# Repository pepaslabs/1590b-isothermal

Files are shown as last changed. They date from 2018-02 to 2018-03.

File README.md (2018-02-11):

# 1590b-isothermal

A "daughter board" which attaches to the bottom of a Hammond 1590B and regulates its temperature at 25C.

- [schematic](kicad/releases/v1/isothermal.pdf)
- [gerber files](kicad/releases/v1)
- [OSHPark link](https://oshpark.com/shared_projects/qRlewBCr)

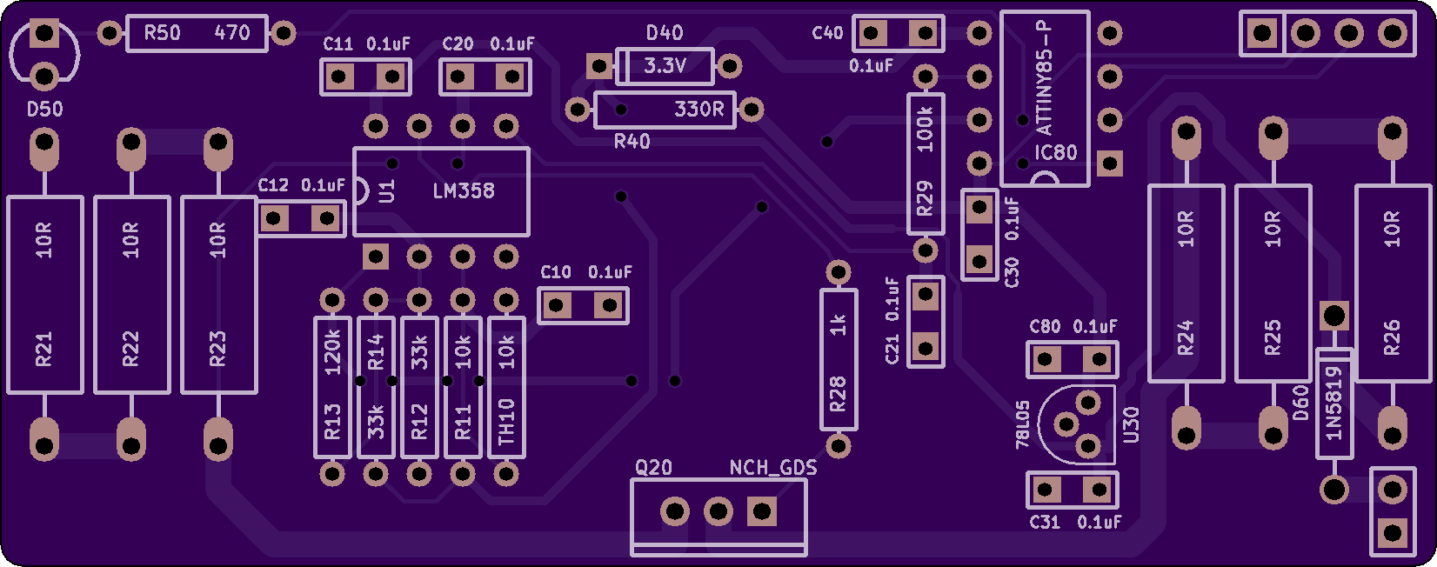
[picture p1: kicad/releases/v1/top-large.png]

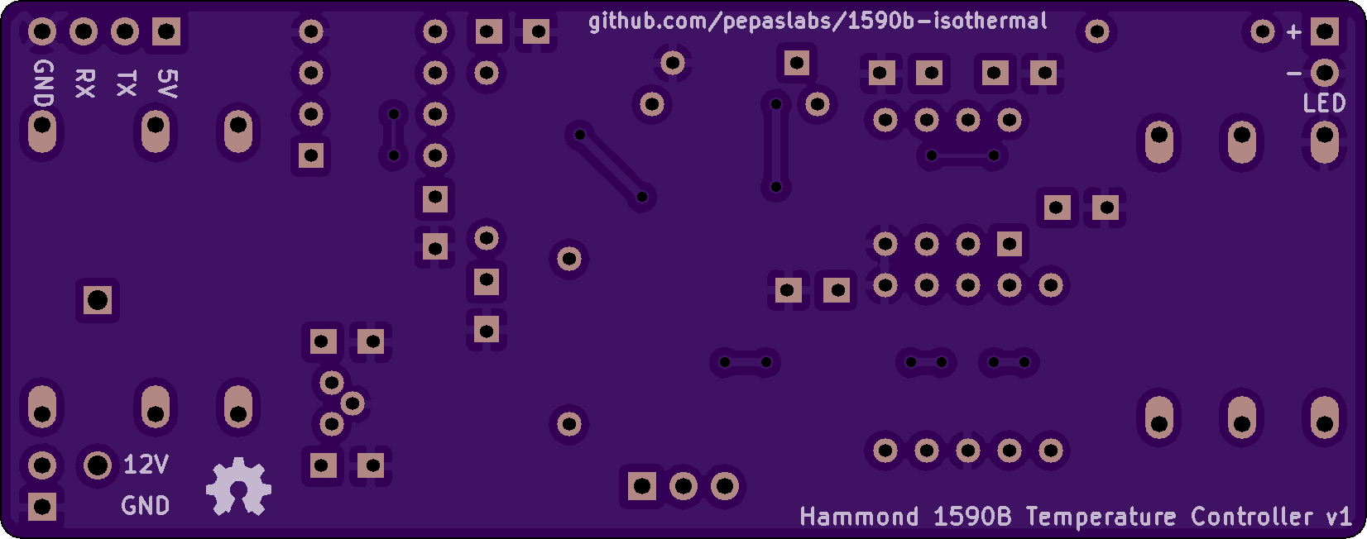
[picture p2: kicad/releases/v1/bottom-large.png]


The resistor values were chosen to map a 20C to 30C window onto (roughly) 0V to 3.3V.

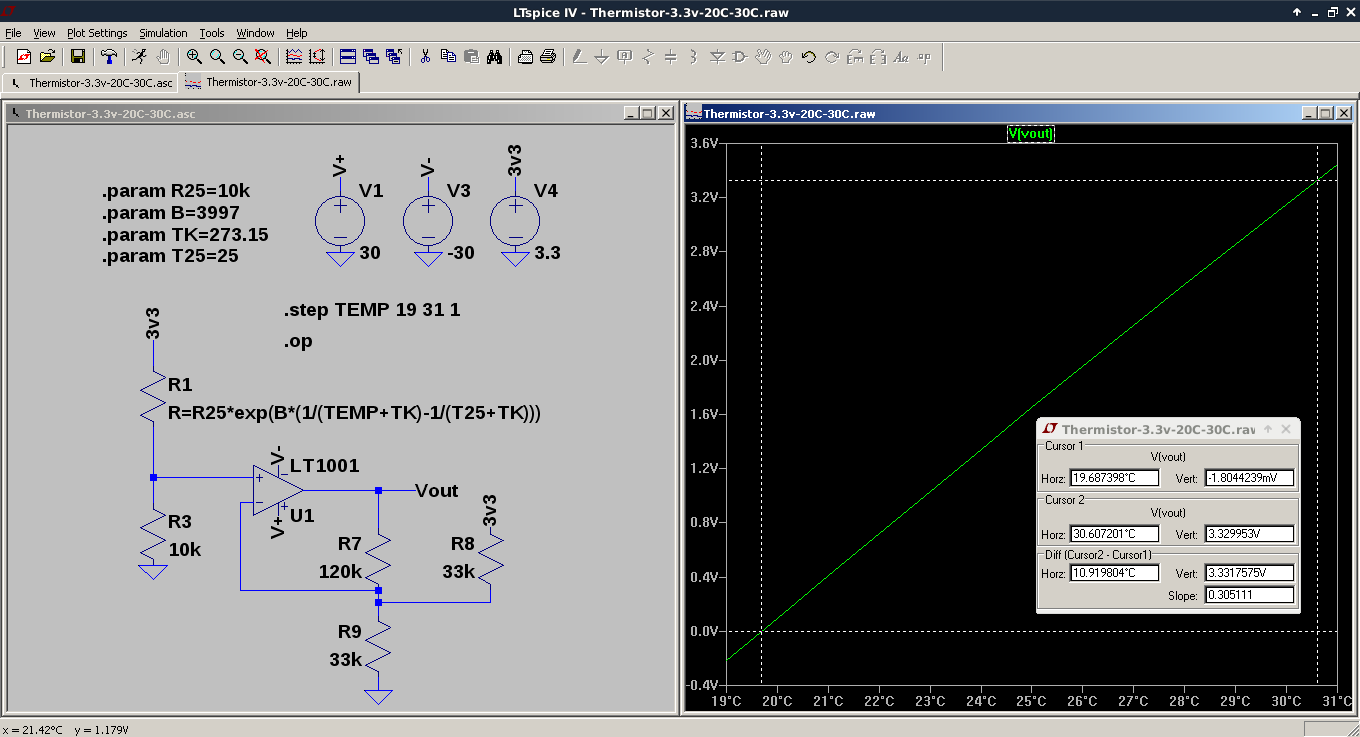
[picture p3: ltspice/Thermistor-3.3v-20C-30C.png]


See also [this link](https://github.com/cellularmitosis/logs/tree/master/20180126-25c-chamber-tuning) for PID tuning and measurements of a similar design (based on MCP9701 rather than thermistors).

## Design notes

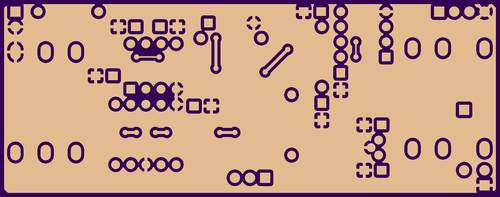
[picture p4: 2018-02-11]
kicad/releases/v1/bottom-copper.png

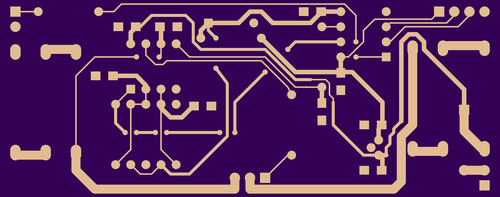
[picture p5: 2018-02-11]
kicad/releases/v1/top-copper.png

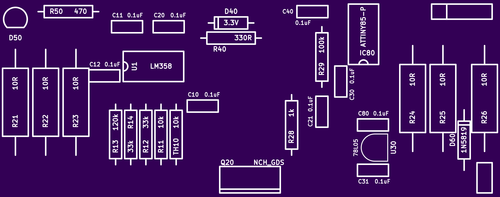
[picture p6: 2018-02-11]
kicad/releases/v1/top-silk.png

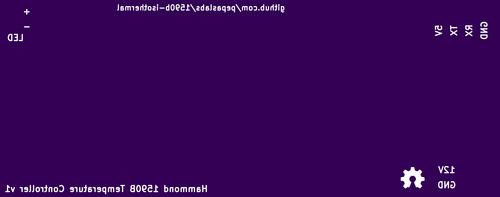
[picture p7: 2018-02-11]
kicad/releases/v1/bottom-silk.png

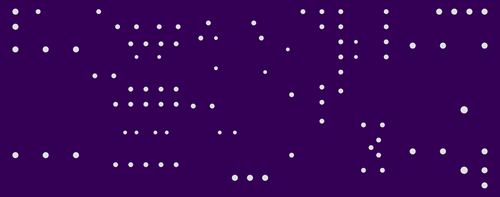
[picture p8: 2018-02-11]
kicad/releases/v1/drills.png

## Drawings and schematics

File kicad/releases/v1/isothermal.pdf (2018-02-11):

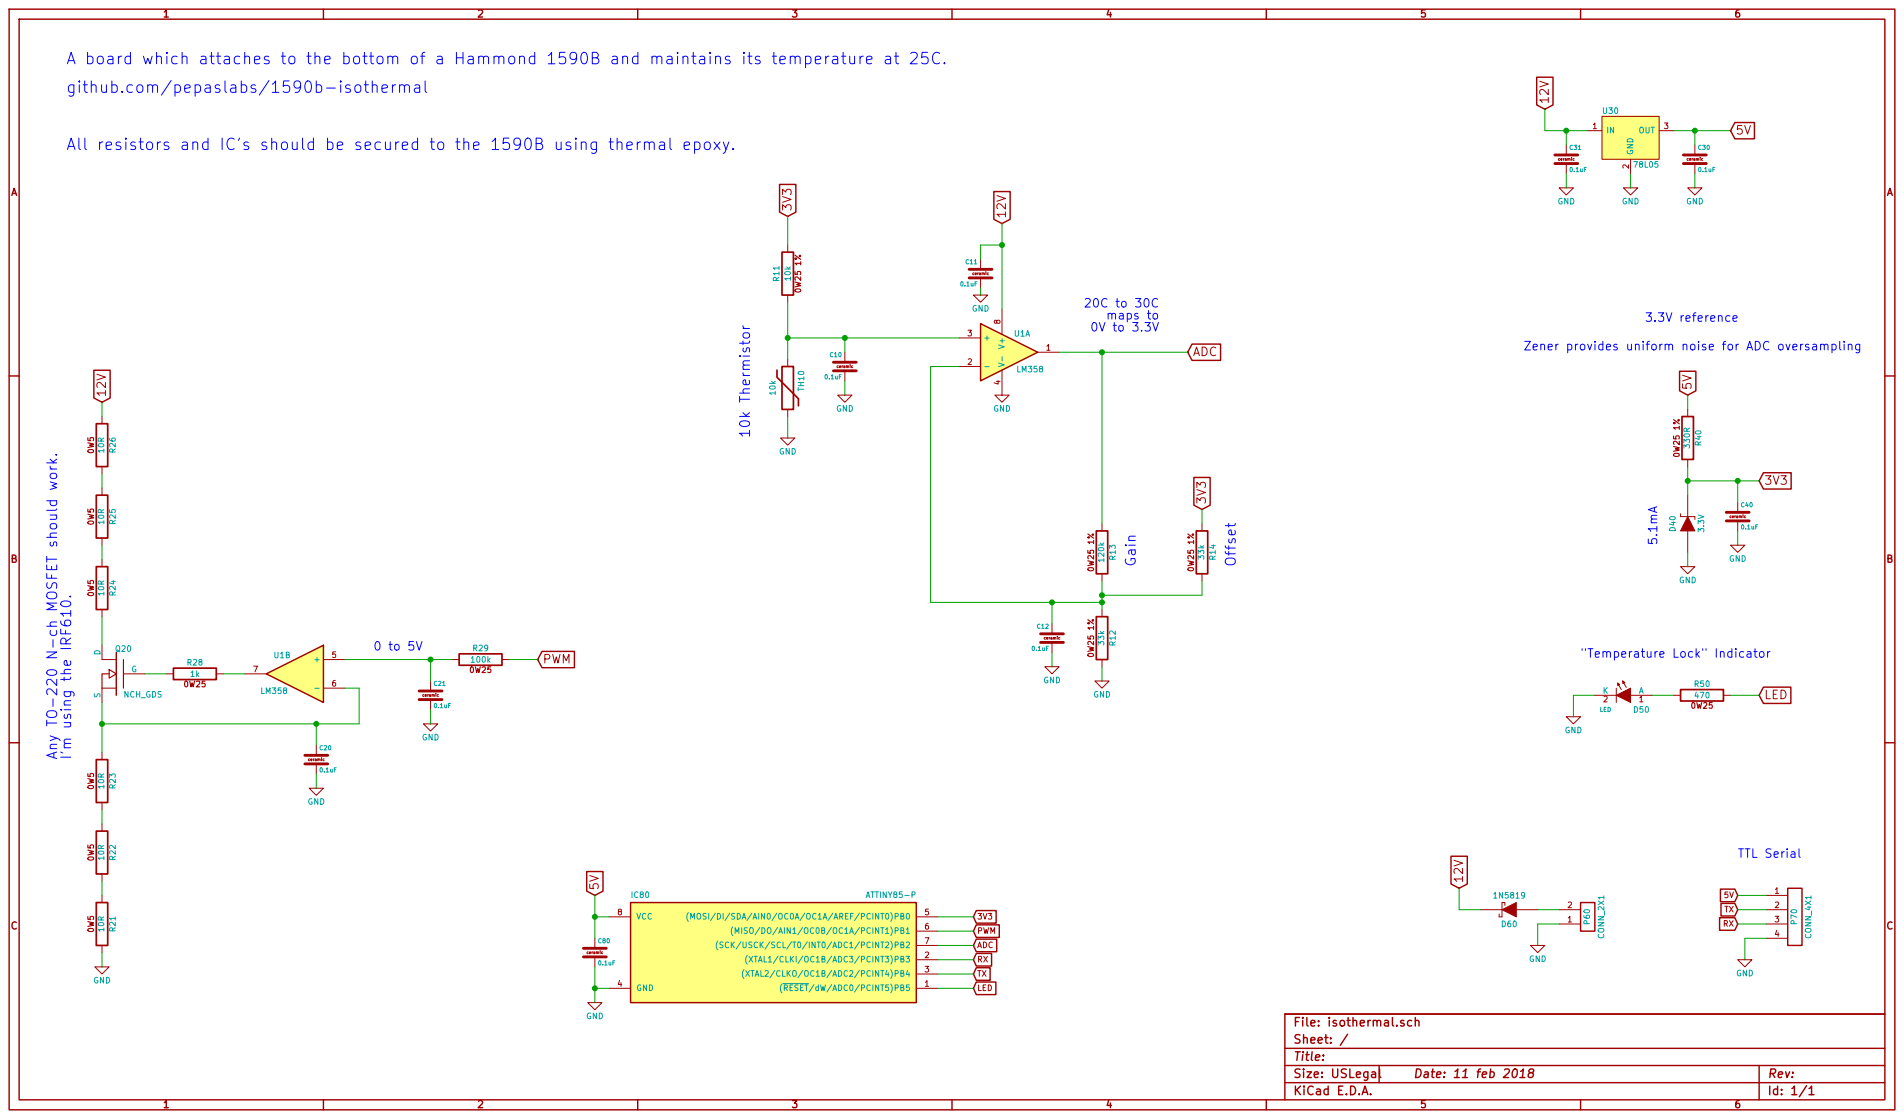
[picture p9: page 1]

All resistors and IC's should be secured to the 1590B using thermal epoxy. Any TO-220 N-ch MOSFET should work. I'm using the IRF610.

GND 3.3V reference Zener provides uniform noise for ADC oversampling Offset

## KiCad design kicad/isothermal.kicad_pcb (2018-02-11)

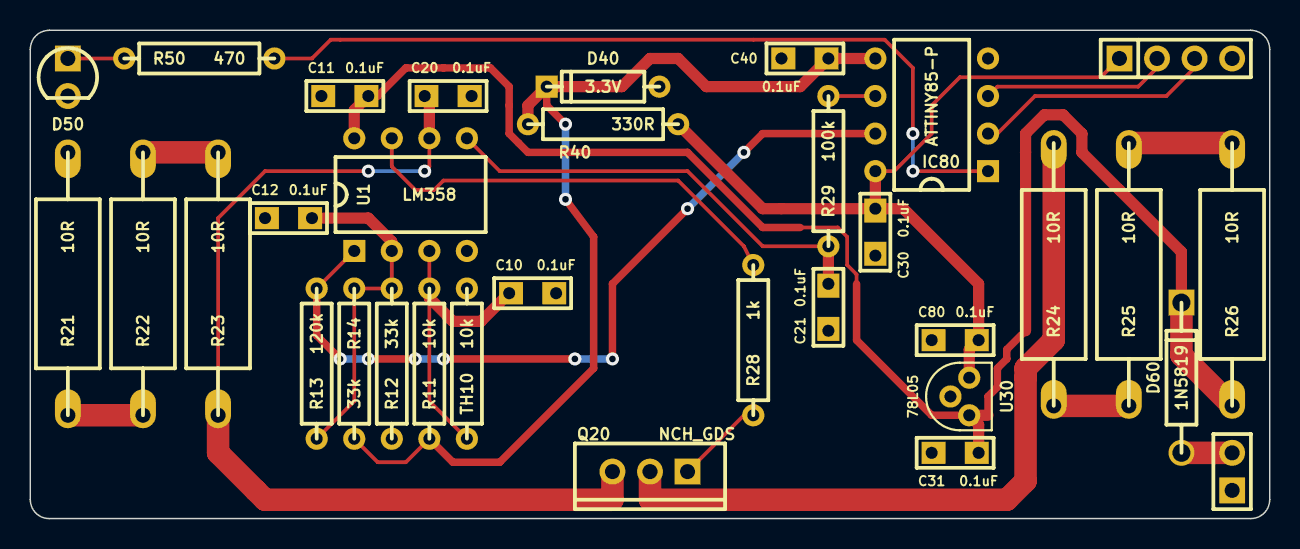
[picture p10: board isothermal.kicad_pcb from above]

Board: 2 copper layers, 83.8 x 33.0 mm, 33 parts (0 on the bottom side), 22 nets.

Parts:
C10, C11, C12, C20, C21, C30, C31, C40, C80: 0.1uF; CERCAP_15_059B_0805
D40: 3.3V; DIODE_SS_059A_03_PL
D50: LED; LED_3MM_069A
D60: 1N5819; DIODE_1A_069A_04_PL
IC80: ATTINY85-P; DIP8_059A_PL
P60: CONN_2X1; SIL-2
P70: CONN_4X1; SIL-4
Q20: NCH_GDS; TO-220_V_069A
R11: 10k; R_AXIAL_0W25_059A_PL
R12, R14: 33k; R_AXIAL_0W25_059A_PL
R13: 120k; R_AXIAL_0W25_059A_PL
R21, R22, R23, R24, R25, R26: 10R; R_AXIAL_1W_PL
R28: 1k; R_AXIAL_0W25_059A_PL
R29: 100k; R_AXIAL_0W25_059A_PL
R40: 330R; R_AXIAL_0W25_059A_PL
R50: 470; R_AXIAL_0W25_059A_PL
TH10: 10k; R_AXIAL_0W25_059A_PL
U1: LM358; DIP8_059A_PL
U30: 78L05; TO-92_U_059A_PL

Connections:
3V3: C40.1, D40.2, IC80.5, R11.1, R14.2, R40.1
5V: C30.1, C80.1, IC80.8, P70.1, R40.2, U30.3
12V: C11.1, C31.1, D60.2, R26.2, U1.8, U30.1
ADC: IC80.7, R13.2, U1.1
GND: C10.2, C11.2, C12.2, C20.2, C21.2, C30.2, C31.2, C40.2, C80.2, D40.1, D50.2, IC80.4, P60.1, P70.4, R12.1, R21.1, TH10.2, U1.4, U30.2
LED: IC80.1, R50.2
unnamed: D60.1, P60.2
unnamed: D50.1, R50.1
unnamed: R22.2, R23.1
unnamed: R21.2, R22.1
unnamed: R25.2, R26.1
unnamed: R24.2, R25.1
unnamed: Q20.2, R24.1
unnamed: C21.1, R29.1, U1.5
unnamed: R28.2, U1.7
unnamed: Q20.1, R28.1
unnamed: C20.1, Q20.3, R23.2, U1.6
unnamed: C10.1, R11.2, TH10.1, U1.3
unnamed: C12.1, R12.2, R13.1, R14.1, U1.2
PWM: IC80.6, R29.2
RX: IC80.2, P70.3
TX: IC80.3, P70.2

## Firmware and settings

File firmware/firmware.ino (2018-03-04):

#include "PID_v1.h"
#include "SoftwareSerial.h"

// --- user-tweakable values:

#define RX 3 // PB3, attiny pin 2
#define TX 4 // PB4, attiny pin 3
#define INPUT_PIN A0 // PB2, attiny pin 7
#define OUTPUT_PIN 1 // PB1, attiny pin 6

uint16_t loop_period = 1000; // in ms

double kp = 4.0;
double ki = 0.4;
double kd = 0.1;

double setpoint = 512;

// ---

double input = 0;
double output = 0;
PID myPID(&input, &output, &setpoint, kp, ki, kd, REVERSE);

SoftwareSerial ser(RX,TX);

uint32_t next_loop_start = 0;

void setup() {

  analogReference(EXTERNAL);
  
  pinMode(INPUT_PIN, INPUT);
  pinMode(OUTPUT_PIN, OUTPUT);
  
  ser.begin(9600); // 9600 8N1

  myPID.SetSampleTime(loop_period);
  myPID.SetMode(AUTOMATIC);

  // print out the CSV header.
  delay(250);
  ser.println("input,output");

  next_loop_start = millis() + loop_period;
}


void loop() {

  if (input != 0) {
    ser.print(input);
    ser.print(",");
    ser.println(output);
  }
  
  // accumulate samples until we only have 50ms of time margin left in this loop
  uint32_t accumulator = 0;
  uint32_t samples = 0;
  while (next_loop_start - millis() > 50) {
    for (uint8_t i = 0; i < UINT8_MAX; i++) {
      accumulator += analogRead(INPUT_PIN);
    }
    samples += UINT8_MAX;
  }
  input = double(accumulator) / double(samples);

  while (myPID.Compute() == false) { continue; }
  analogWrite(OUTPUT_PIN, output);

  while (millis() <= next_loop_start) { delay(1); }
  while (millis() > next_loop_start) { next_loop_start += loop_period; }
}

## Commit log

2018-02-11 board shots
2018-02-11 used wider holes for the input protection diode.
    [isothermal-B_Cu.gbl, isothermal-B_Mask.gbs, isothermal-B_SilkS.gbo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]
